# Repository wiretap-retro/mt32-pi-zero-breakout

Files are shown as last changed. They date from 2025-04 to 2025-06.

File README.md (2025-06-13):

# mt32-pi Zero Breakout
A small breakout board for custom mt32-pi projects using a Raspberry Pi Zero 2 W. 
\
\
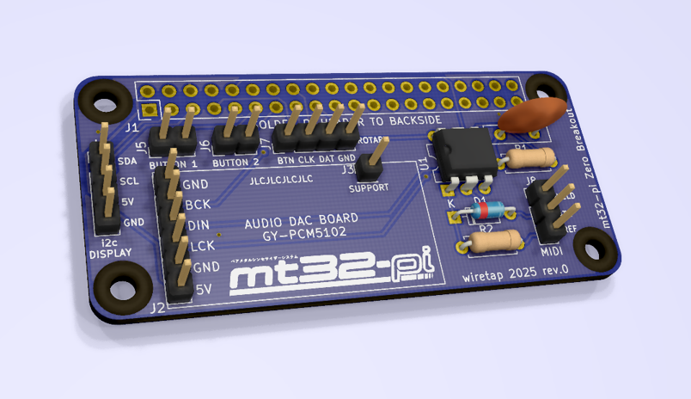
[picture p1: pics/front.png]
front


## Info
The core project design is attributed to Dale Whinham and his awesome mt32-pi project. Repo link: https://github.com/dwhinham/mt32-pi
\
\
This PCB I designed is a breakout board style header for small DIY mt32-pi projects. There are no clunky headers or connectors to take up extra space. It allows for low clearance if you direct solder as many components as you can. 
\
\
I have included the full KiCad project along with the Mouser Cart, BOM, and Gerber files for ease of upload. The design is minimalist to allow you flexibility for connectivity. I plan on using this with mostly panel-mount style connectors in my enclosure, so all I needed was solder points or 2.54mm spacing dupont connectors for everything.
\
\
Designed for use with my 5.25" bay panel found here: https://github.com/wiretap-retro/mt32-pi-bay

## Parts
The parts not listed in the BOM that you need are as follows:
- GY-PCM5102 Digital to Analog Audio Converter
- Raspberry Pi Zero 2 W
- Any other components for your specific project such as external buttons/encoders, external connectors, and i2c screens.

\
Please read the original mt32-pi repository linked in the information section for compatible screens, encoders, etc..

## Revision Notes
2025-05-03 --- Updated BOM to correct capacitor C1 diameter/size.

## License
This project uses the UNLICENSE. Feel free to do what you want with it. Check over the project before ordering. Build at your own risk.

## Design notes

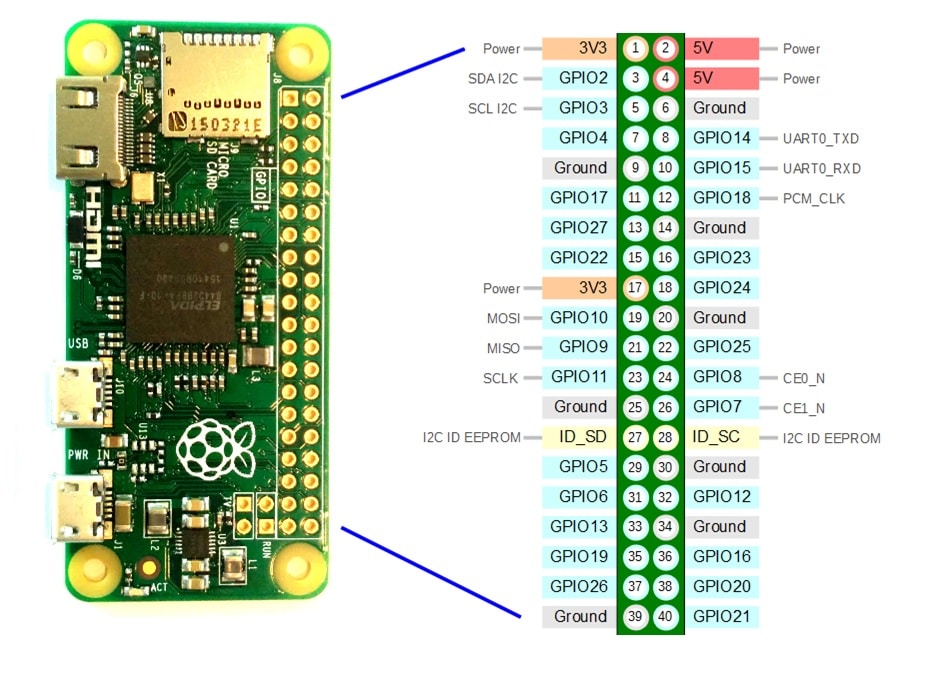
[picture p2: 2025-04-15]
pics/Raspberry-PI-Zero-Pinout.jpg

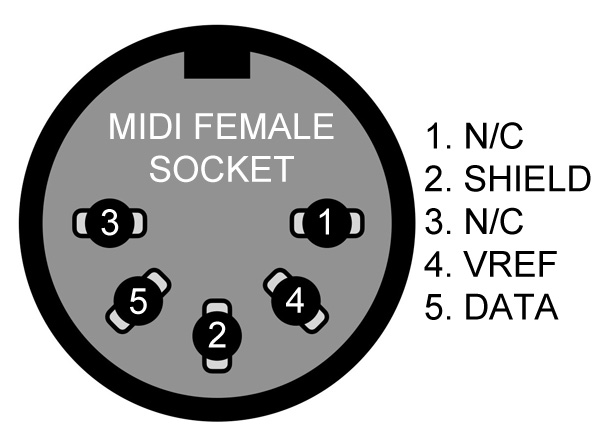
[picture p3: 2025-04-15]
pics/MIDI-socket.jpeg

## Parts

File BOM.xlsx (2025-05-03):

Reference | Quantity | Value | Footprint | Manufacturer | Part No. | Notes
C1 | 1 | 100nF | Capacitor_THT:C_Disc_D9.0mm_W2.5mm_P5.00mm | Kyocera | AR211C104K4RTR2 | 0.1uF / 100nF
D1 | 1 | 1N4148 | Diode_THT:D_DO-35_SOD27_P7.62mm_Horizontal | Onsemi | 1N4148
J1 | 1 | Raspberry_Pi_0_2_3 | Connector_PinHeader_2.54mm:PinHeader_2x20_P2.54mm_Vertical | Adafruit | 2222 | This is a female header. Check how you want to connect it first! Direct solder for slim fit.
J2 | 1 | DAC Board | Connector_PinHeader_2.54mm:PinHeader_1x06_P2.54mm_Vertical | Samtec | TSW-150-07-T-S | Use part of a Samtec TSW-150-07-T-S. Or solder wires direct.
J3 | 1 | SUPPORT | Connector_PinHeader_2.54mm:PinHeader_1x01_P2.54mm_Vertical | Samtec | TSW-150-07-T-S | Use part of a Samtec TSW-150-07-T-S. Or solder wires direct.
J4 | 1 | DISPLAY | Connector_PinHeader_2.54mm:PinHeader_1x04_P2.54mm_Vertical | Samtec | TSW-150-07-T-S | Use part of a Samtec TSW-150-07-T-S. Or solder wires direct.
J5 | 1 | BUTTON 1 | Connector_PinHeader_2.54mm:PinHeader_1x02_P2.54mm_Vertical | Samtec | TSW-150-07-T-S | Use part of a Samtec TSW-150-07-T-S. Or solder wires direct.
J6 | 1 | BUTTON 2 | Connector_PinHeader_2.54mm:PinHeader_1x02_P2.54mm_Vertical | Samtec | TSW-150-07-T-S | Use part of a Samtec TSW-150-07-T-S. Or solder wires direct.
J7 | 1 | ROTARY | Connector_PinHeader_2.54mm:PinHeader_1x04_P2.54mm_Vertical | Samtec | TSW-150-07-T-S | Use part of a Samtec TSW-150-07-T-S. Or solder wires direct.
J8 | 1 | MIDI | Connector_PinHeader_2.54mm:PinHeader_1x03_P2.54mm_Vertical | Samtec | TSW-150-07-T-S | Use part of a Samtec TSW-150-07-T-S. Or solder wires direct.
R1 | 1 | 1k | Resistor_THT:R_Axial_DIN0207_L6.3mm_D2.5mm_P7.62mm_Horizontal | TE Connectivity | LR0204F1K0
R2 | 1 | 220 | Resistor_THT:R_Axial_DIN0207_L6.3mm_D2.5mm_P7.62mm_Horizontal | TE Connectivity | LR0204F220R
U1 | 1 | H11L1 | Package_DIP:DIP-6_W7.62mm | Onsemi | H11L1M
Mouser Cart Link: |  | Link (https://www.mouser.com/Tools/Project/Share?AccessID=90b9fc83c6)

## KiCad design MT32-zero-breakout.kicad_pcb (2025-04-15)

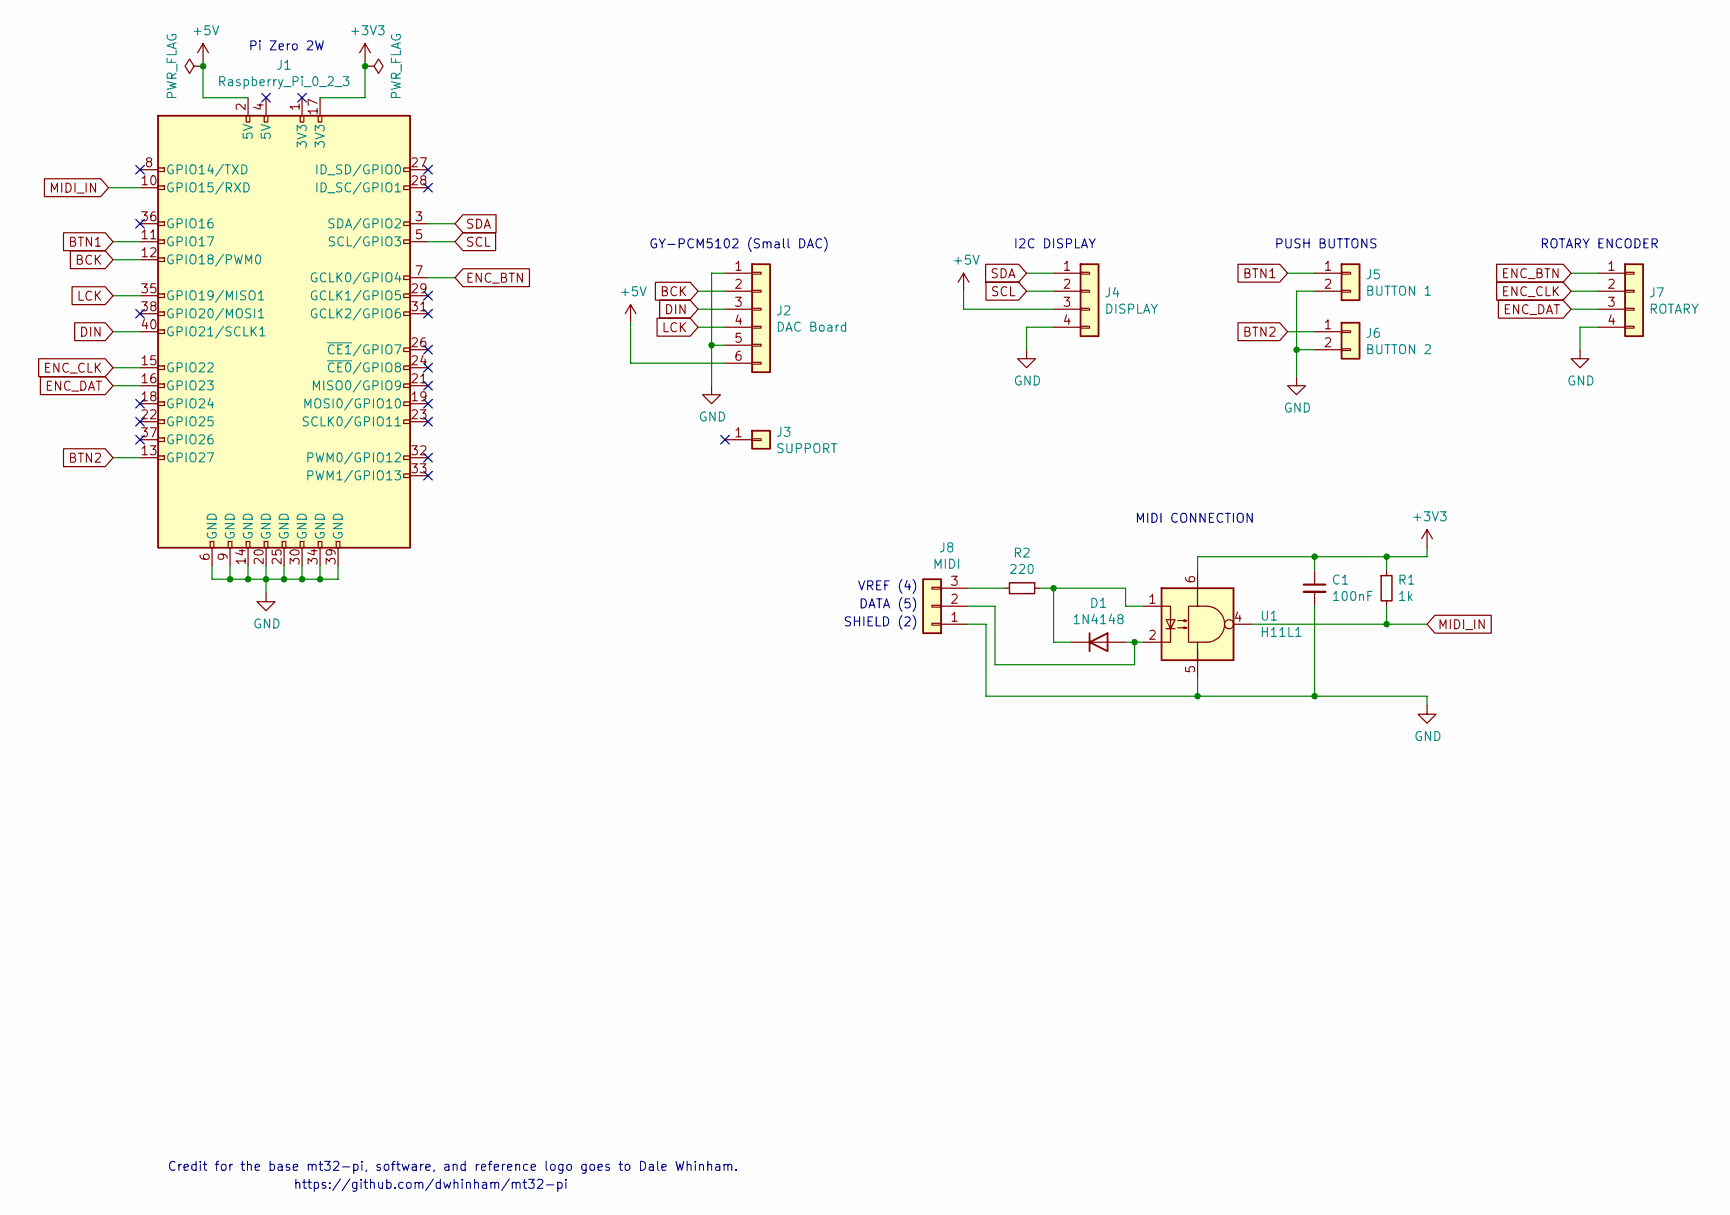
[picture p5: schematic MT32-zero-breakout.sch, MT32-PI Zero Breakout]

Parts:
C1: 100nF; C_Disc_D9.0mm_W2.5mm_P5.00mm; Part No. 565R20GAP10
D1: 1N4148; D_DO-35_SOD27_P7.62mm_Horizontal
J1: Raspberry_Pi_0_2_3; PinHeader_2x20_P2.54mm_Vertical
J2: DAC Board; PinHeader_1x06_P2.54mm_Vertical
J3: SUPPORT; PinHeader_1x01_P2.54mm_Vertical
J4: DISPLAY; PinHeader_1x04_P2.54mm_Vertical
J5: BUTTON 1; PinHeader_1x02_P2.54mm_Vertical
J6: BUTTON 2; PinHeader_1x02_P2.54mm_Vertical
J7: ROTARY; PinHeader_1x04_P2.54mm_Vertical
J8: MIDI; PinHeader_1x03_P2.54mm_Vertical
R1: 1k; R_Axial_DIN0207_L6.3mm_D2.5mm_P7.62mm_Horizontal
R2: 220; R_Axial_DIN0207_L6.3mm_D2.5mm_P7.62mm_Horizontal
U1: H11L1; DIP-6_W7.62mm

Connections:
+3V3: C1.1, J1.17 (3V3), R1.1, U1.6
+5V: J1.2 (5V), J2.6, J4.3
BCK: J1.12 (GPIO18/PWM0), J2.2
BTN1: J1.11 (GPIO17), J5.1
BTN2: J1.13 (GPIO27), J6.1
DIN: J1.40 (GPIO21/SCLK1), J2.3
ENC_BTN: J1.7 (GCLK0/GPIO4), J7.1
ENC_CLK: J1.15 (GPIO22), J7.2
ENC_DAT: J1.16 (GPIO23), J7.3
GND: C1.2, J1.6 (GND), J1.9 (GND), J1.14 (GND), J1.20 (GND), J1.25 (GND), J1.30 (GND), J1.34 (GND), J1.39 (GND), J2.1, J2.5, J4.4, J5.2, J6.2, J7.4, J8.1, U1.5
LCK: J1.35 (GPIO19/MISO1), J2.4
MIDI_IN: J1.10 (GPIO15/RXD), R1.2, U1.4
unnamed: D1.1 (K), R2.1, U1.1
unnamed: D1.2 (A), J8.2, U1.2
unnamed: J8.3, R2.2
SCL: J1.5 (SCL/GPIO3), J4.2
SDA: J1.3 (SDA/GPIO2), J4.1

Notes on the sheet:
Pi Zero 2W
GY-PCM5102 (Small DAC)
I2C DISPLAY
PUSH BUTTONS
ROTARY ENCODER
SHIELD (2)
DATA (5)
VREF (4)
MIDI CONNECTION
https://github.com/dwhinham/mt32-pi
Credit for the base mt32-pi, software, and reference logo goes to Dale Whinham.

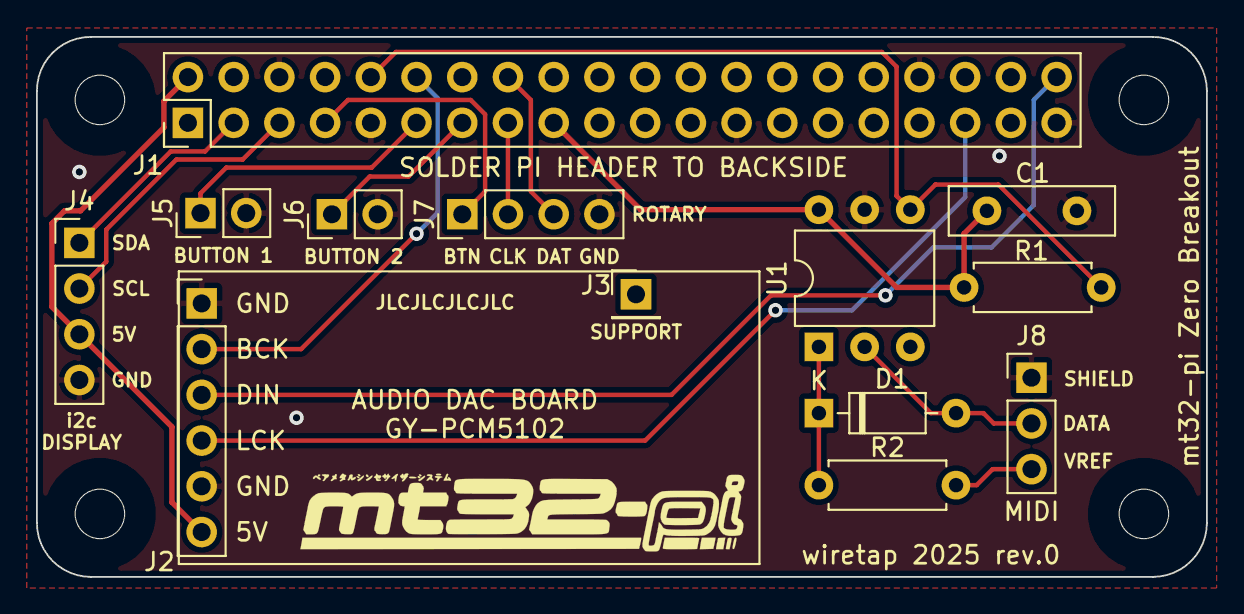
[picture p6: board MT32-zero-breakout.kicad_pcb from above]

Board: 2 copper layers, 65.0 x 30.0 mm, 13 parts (0 on the bottom side), 17 nets.
